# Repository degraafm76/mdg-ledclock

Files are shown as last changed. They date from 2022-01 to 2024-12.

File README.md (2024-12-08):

# MDG Ledclock model 1
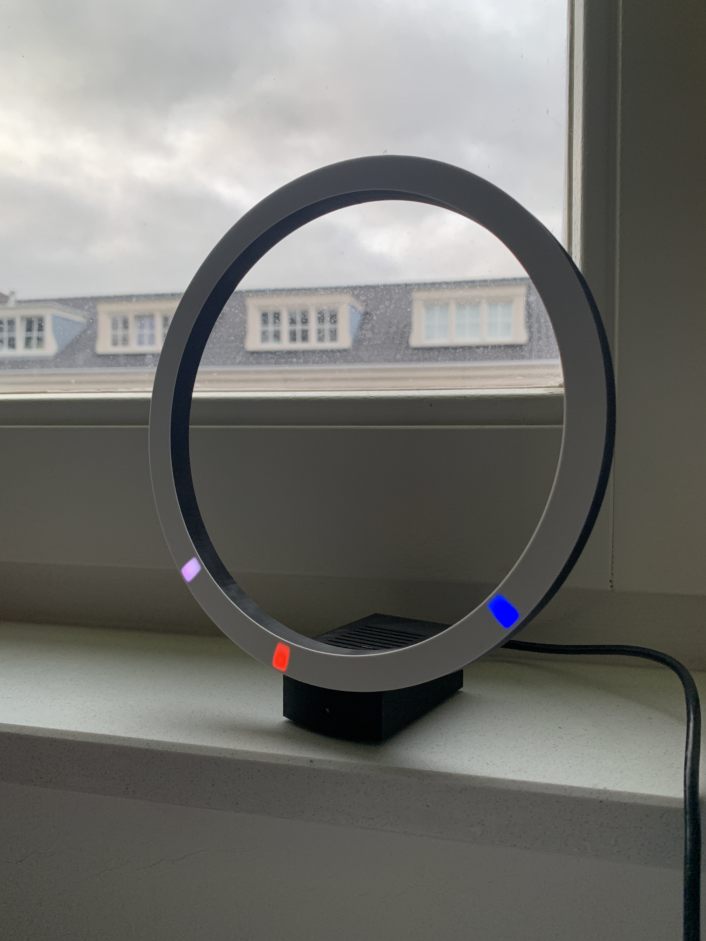
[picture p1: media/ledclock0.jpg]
MDG Ledclock

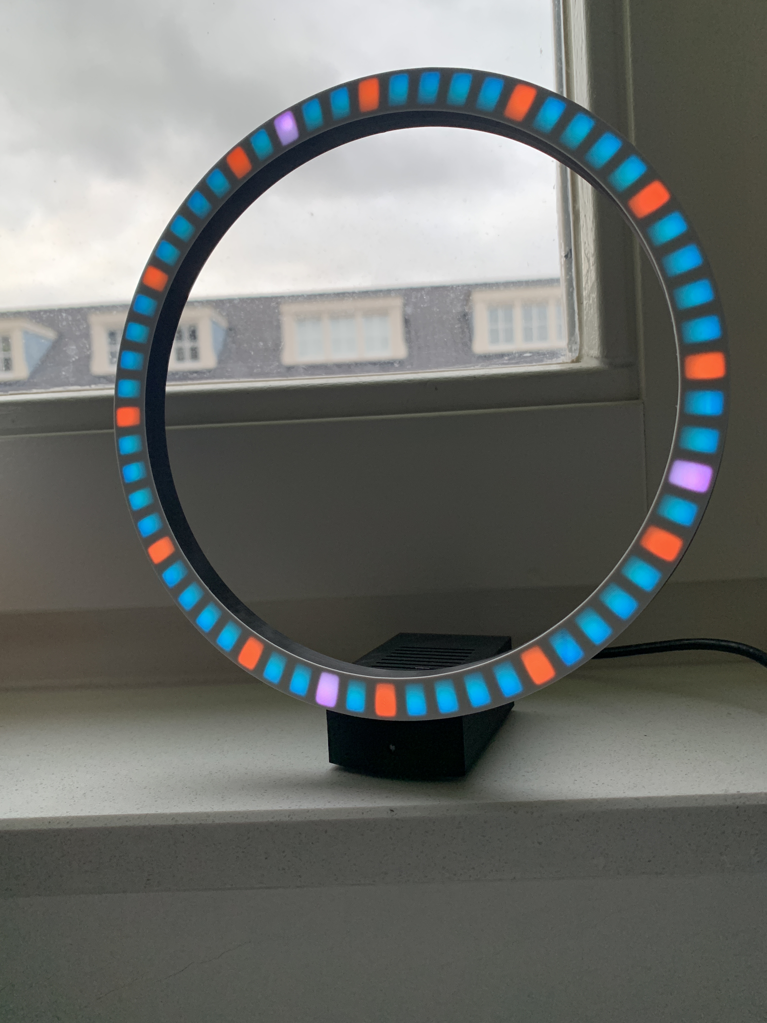
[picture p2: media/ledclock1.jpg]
MDG Ledclock

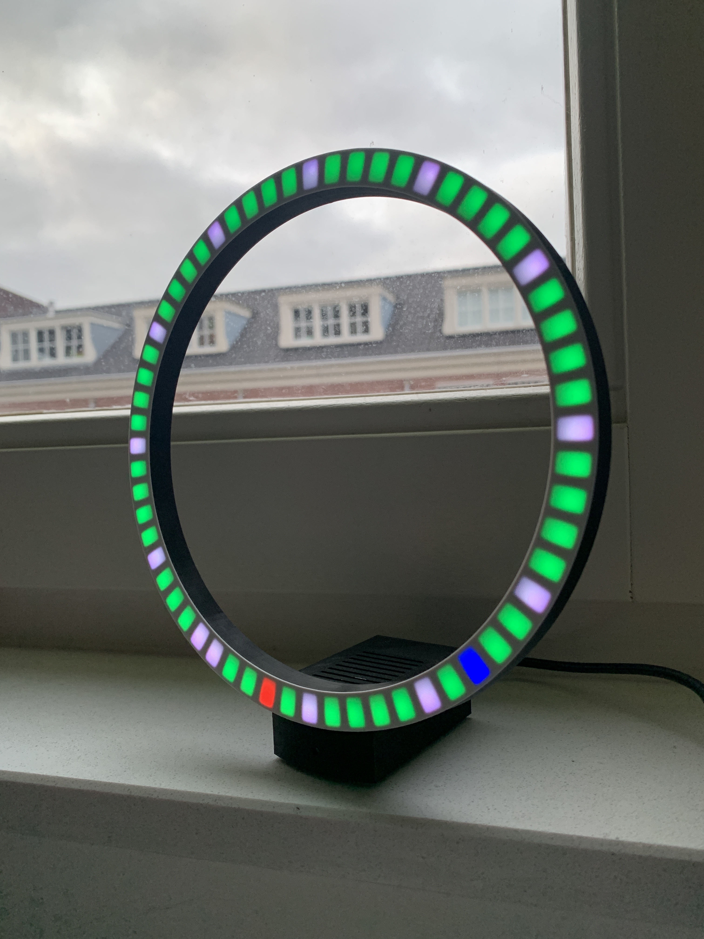
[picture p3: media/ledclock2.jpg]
MDG Ledclock

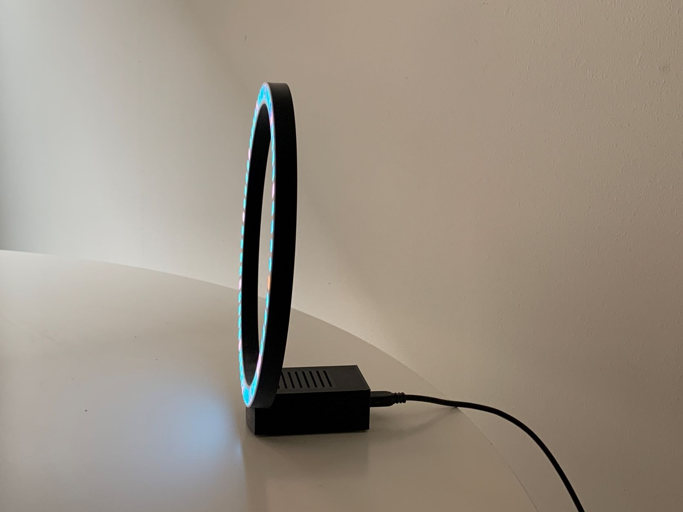
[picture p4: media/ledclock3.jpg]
MDG Ledclock


An ESP8266 based LED clock which can be controlled by HTTP and MQTT. 
Tested with Home Assistant but other domotica systems with MQTT support should work fine.

The Hardware is also compatible with the WLED project see > https://kno.wled.ge/

# Ok cool, I want one!
What are your options:

1. Buy a ready to use MDG ledclock [Etsy: MDG Led clock model 1](https://www.etsy.com/nl/listing/986543633/mdg-led-klok-model-1?ref=listings_manager_grid)
2. Source your own electronics, 3D print the parts and build it yourself.

If you like my work please consider donating to support my work.



# Electronic parts
* 1 NodeMCU ESP8266 V2
* 1 TEMT6000 Ambient light sensor
* 1 1000uF Capacitor 24V
* 1 330R 0.5W Resistor 
* 1 SK6812 LED ring 60 (https://www.tinytronics.nl/shop/nl/verlichting/ringen-en-modules/sk6812-digitale-5050-rgb-led-ring-60-leds-wit) or (https://nl.aliexpress.com/item/1005002090813354.html?gatewayAdapt=glo2nld&spm=a2g0o.9042311.0.0.27424c4dx34xlJ)
* 1 USB 5V adapter minimum 1A

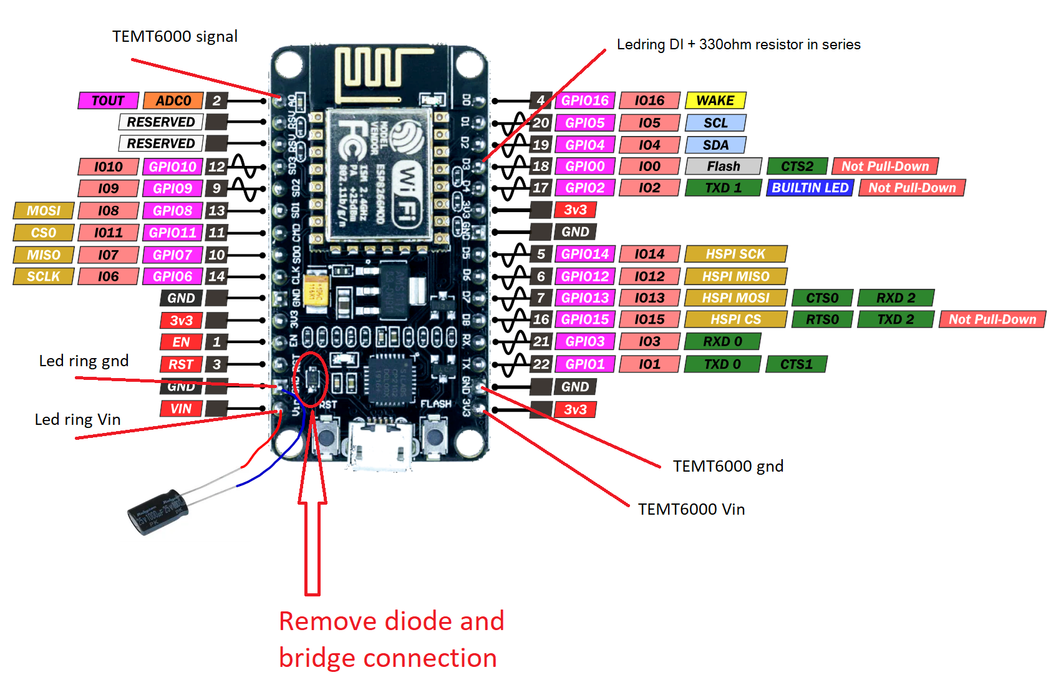
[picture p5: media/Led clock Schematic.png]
Schematic

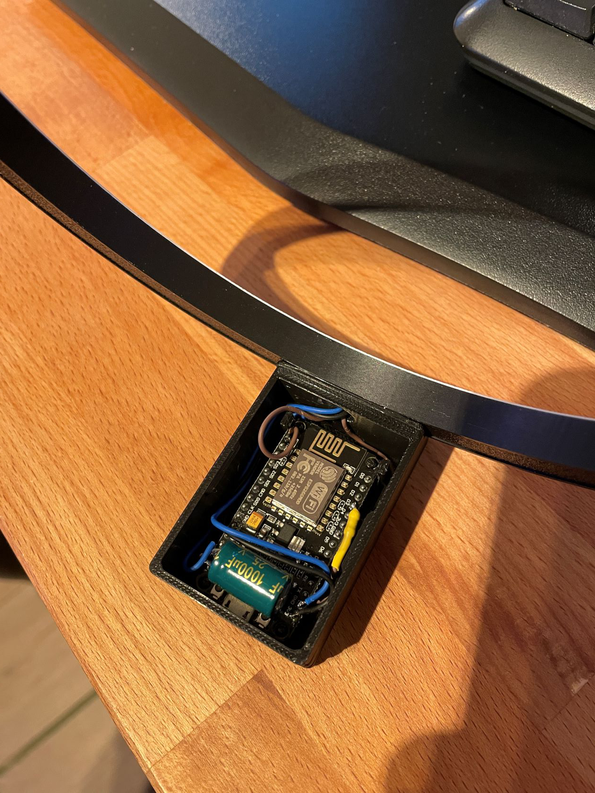
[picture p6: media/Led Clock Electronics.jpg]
Suggested wiring


# Printing parts
The parts are designed with PLA in mind. Nozzle width must be 0.4mm and layer hight 0.2mm. For the front ring and case supports on build plate are needed.

The front ring must be printed in multiple colors. The first 3 layers (0.6mm) white and the rest of the layers black. If you don't know how to print multicolor objects with your printer I suggest you take a look at: https://www.youtube.com/watch?v=1nBnVtOEAiY

The [models](https://github.com/degraafm76/mdg-ledclock/tree/main/STL) of this clock are licenced [Attribution-NonCommercial-ShareAlike 4.0 International (CC BY-NC-SA 4.0)](https://creativecommons.org/licenses/by-nc-sa/4.0/legalcode) This license lets others remix, adapt, and build upon my work non-commercially, as long as you credit me and license your new creations under the identical terms.

# Setup the clock
See https://github.com/degraafm76/mdg-ledclock/blob/main/DOC/MDG%20-%20Ledclock%20(model%201).pdf

# Serial configuration
All configuration settings (wifi/mqtt/timezone) can be set with a serial connection. Use 115200 baud

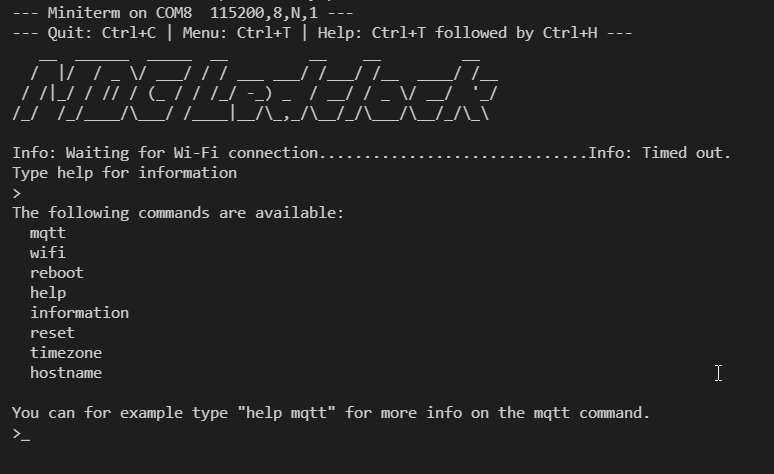
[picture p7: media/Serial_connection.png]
Serial Connection


# Update software
There are 2 options to update the clock.

1. Install Visual Studio code with platform.io and compile/upload the software to the clock. You can find the latest release here https://github.com/degraafm76/mdg-ledclock/releases
2. Download the bin file from the latest release and flash the file to the clock with ESP home flasher https://github.com/esphome/esphome-flasher/releases

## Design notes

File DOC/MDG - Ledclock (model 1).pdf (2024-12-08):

# MDG LEDCLOCK (MODEL 1)

# QUICKSTART GUIDE V1.6 12-2024

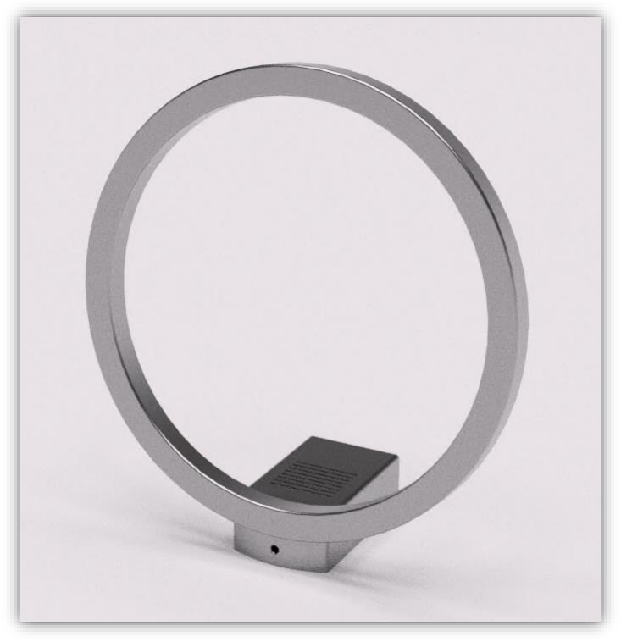
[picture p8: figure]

1 INDEX

2 INTRODUCTION

First of all thank you for buying this handmade clock which is designed and manufactured in a small workshop in the Netherlands.

I hope you have much fun using this clock!

HOW TO GET HELP

If you have any problems with this clock, please leave us a message at support@mdg-design.nl and we will try to help you out.

Latest information and software version can be found at degraafm76/mdg-ledclock (github.com) (https://github.com/degraafm76/mdg-ledclock)

A WORD OF CAUTION

The body of the clock is made on a 3D-printer with PLA plastic. PLA has a melting temperature of about 60C/140F. Please don’t leave the clock in a car on a hot summer day, or put it next to a heat source. This may deform or permanently damage your clock.

3 SETUP YOUR CLOCK

Power up your clock by connecting a micro USB cable¹ to an USB 5V power source¹ with an output of at least 1A. Most phone and tablet USB chargers should work, there is no risk in damaging the clock if an USB charger is used with an output of less than 1A but the clock won’t function correctly.

When the clock is powered on, minutes 0 to 29 will light up white and minute 30 red. This will take about 30 seconds. The red light means that there is no working Wi-Fi connection, and is expected when turning the clock on for the first time. Follow the steps in 3.1 to connect to and configure your clock.

Note: 5 seconds after the red light the clock starts running but of course not on time.

1 Not included

3.1 CONNECTING TO THE CLOCK

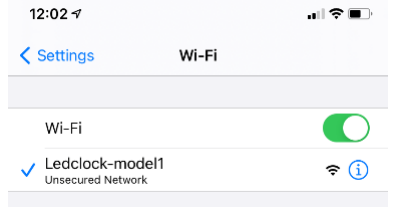
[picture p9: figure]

When the clock cannot connect to a Wi-Fi network, or the clock is not configured, the clock will start a Wi-Fi network with the
SSID ‘MDG-Ledclock1’. Connect to this Wi-Fi network from your mobile phone or pc, no Wi-Fi key is needed in the latest version of the clock (the key for older versions can be found on the bottom of the clock)
Note: do not select the option to auto connect to this network.

When you have a connection to the Wi-Fi network ‘MDG-Ledclock1’ open a browser on the device that has a connection with the Wi-Fi network ‘MDG-Ledclock1’ and go to the following URL: http://ledclock.local. When the URL http://ledclock.local doesn’t work, you can try to connect to the URL: http://192.168.4.1

*There is a know issue where the website of the clock doesn’t open in safari on the latest iPhone versions ( cannot parse error). Please use another browser such as Google Chrome until this issue is fixed.

After a couple of seconds the page as shown in below picture should appear. Open the settings page and follow the instructions in chapter 3.2 tot setup your clock.

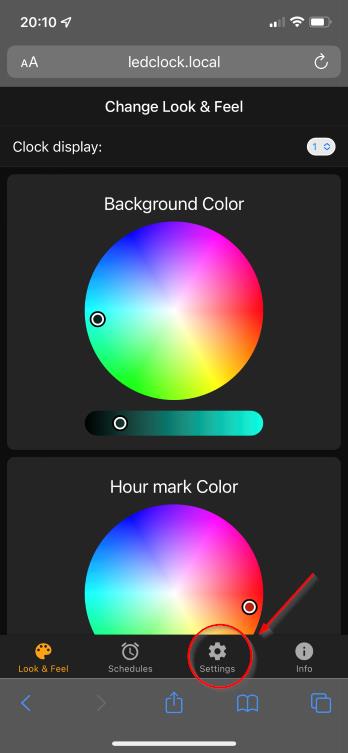
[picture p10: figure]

3.2 SETUP YOUR CLOCK

Press the Scan Networks button (1) and wait until a list of Wi-Fi networks appears. Select your Wi-Fi network and type your Wi-Fi password.

Select your time zone (2) scroll down and press the Save & Reboot button (3). You can leave the MQTT fields empty for now. Wait until you see the clock running with the correct time and continue to chapter 4

Note: It can take some time for the clock to show up after there is a Wi-Fi connection (a couple of white leds, and one green)

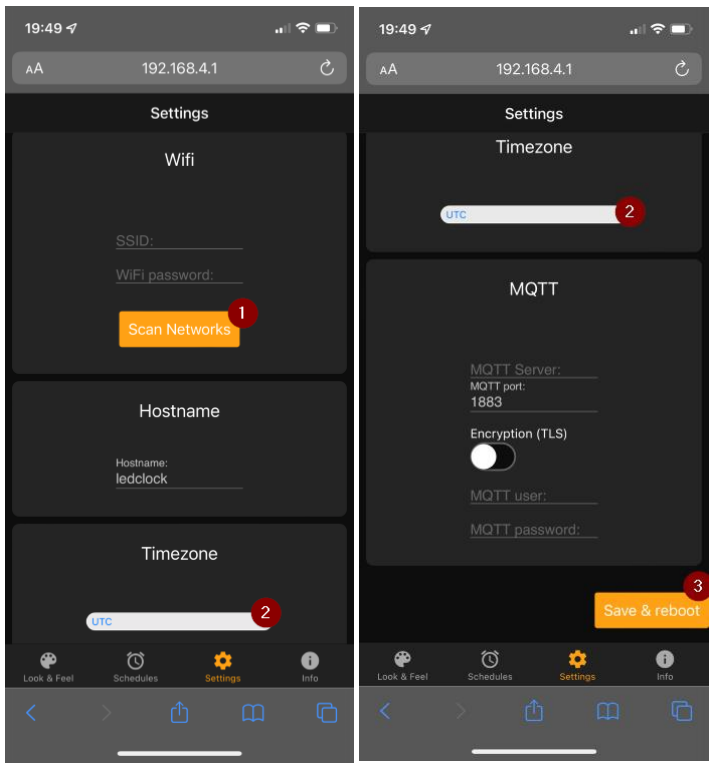
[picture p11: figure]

Optional settings*

Hostname
When needed (for example when you have multiple MDG-clocks) you can change the hostname of the clock. When changing the hostname, make sure to only use numbers and letters. Also take a note of the hostname because you need it to connect to the clock. When you change the hostname the URL becomes http://<yourhostname>.local

MQTT
MQTT configuration is optional. If you know what an MQTT client is, see chapter 5 for configuration, otherwise leave all MQTT fields default.

4 USING YOUR CLOCK

This chapter describes how you can connect to the clock, how to create different clock displays and how to create schedules to change the clock display after you have setup the clock as described in chapter 3

4.1 CONNECTING TO THE CLOCK

Open a web browser and connect to http://ledclock.local, after some time the below interface should appear¹.

1: Make sure you are disconnected from the clock’s Wi-fi network and are connected to you own Wi-Fi network. If you changed the hostname as shown in 3.2, please use this to connect to the clock for example http://yourhostname.local

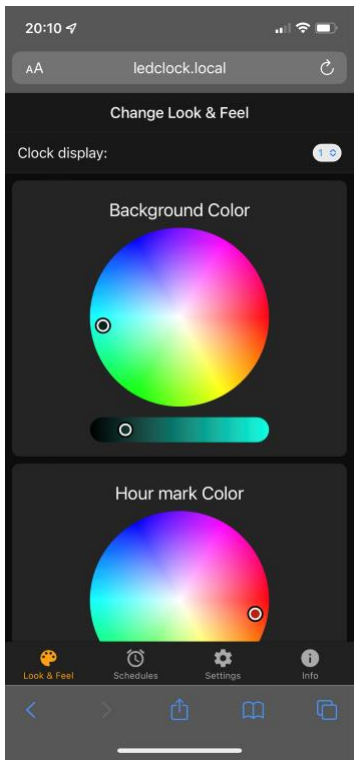
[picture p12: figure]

When the above connection method doesn’t work, lookup the clock’s IP-address in your router or DHCP server. When you have found the IP-address of the clock, connect to it with the URL http://x.x.x.x where x.x.x.x is the IP-address of your clock.

4.2 CREATE DIFFERENT CLOCK DISPLAYS

You can create 8 different clock displays and store them in the clock. First select a clock display number, change the colors and settings like auto brightness the way you want them and press the save button.

Note: Out of the box all 8 position have the same default display colors (blue background, red hours marks and white hour, minute and second hand)

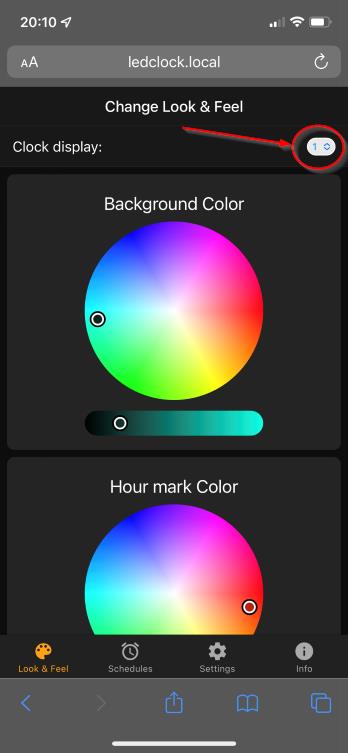
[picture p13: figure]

4.3 CHANGE DISPLAY SCHEDULES

It is possible to change the clock display at specific times. For example: you can have a bright colorful clock display during the day and a very dim display during the night.

To create a schedule open the Schedules tab and click on one of the schedules. Select the time (1) and display number (2) (one of the displays you created in 4.2) and make sure the active switch (3) is on. You can create a maximum of 12 schedules. If you like to disable a specific schedule at a later time set the active switch to off (3).

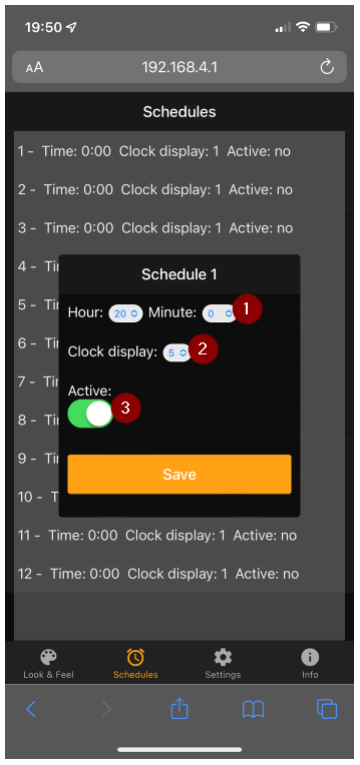
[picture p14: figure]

5 MQTT

When you have a home automation solution which can function as an MQTT broker for example Home Assistant or Homy u can optionally configure the clock as an MQTT client. This way you can control the clock with your home automation solution.

5.1 MQTT CONFIGURATION

Fill in your MQTT broker hostname or IP-address. Fill in your MQTT broker port in, default ports are 1883 (unencrypted) and 8883 (encrypted). If you have MQTT encryption configured on the broker you can enable encryption (TLS). Be aware that when TLS is enabled that the webserver will be disabled.

See chapter 5.5 for TLS notes

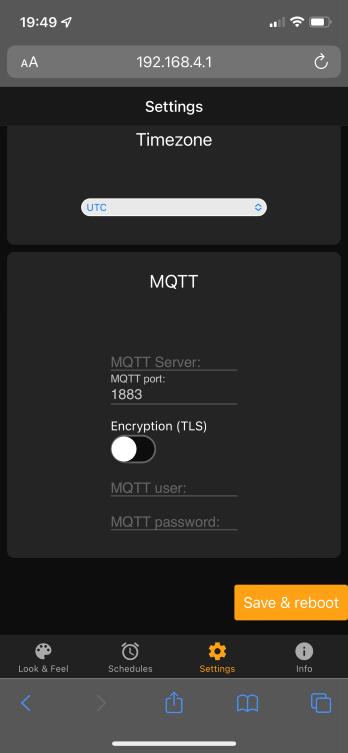
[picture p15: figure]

5.2 MQTT TOPICS

Commands over MQTT are issued to the ledclock by using the topics and JSON payloads described in this chapter. Replace [hostname] with the configured hostname this is by default: ledclock.

5.2.1 DISPLAY

Display Topics
State topic: [hostname]/display/state Command topic: [hostname]/ display /set

On/Off
JSON Payload:
{
"state": "ON|OFF"
}

5.2.2 BACKGROUND

Background Topics
State topic: [hostname]/background/state Command topic: [hostname]/background/set

On/Off
JSON Payload:
{
"state": "ON|OFF"
}

Brightness
JSON Payload:
{
"state": "ON",
"brightness": <1 to 100>
}

Color
JSON Payload:
{
"state": "ON",
"color": {
"r": 0 to 255,
"g": 0 to 255,
"b": 0 to 255
}
}

Effects
{
"state": "ON",
"effect": "<effect>"
}

Effects: <rgb, rainbow, bpm>

5.2.3 HOURMARKS

Hourmarks topics
State topic: [hostname]/hourmarks/state Command topic: [hostname]/hourmarks/set

On/Off
JSON Payload:
{
"state": "ON|OFF"
}

Brightness
JSON Payload:
{
"state": "ON",
"brightness": 1 to 100
}

Color
JSON Payload:
{
"state": "ON",
"color": {
"r": 0 to 255,
"g": 0 to 255,
"b": 0 to 255
}
}

5.2.4 HOUR

Hour topics
State topic: [hostname]/hour/state Command topic: [hostname]/hour/set

On/Off
JSON Payload:
{
"state": "ON|OFF"
}

Brightness
JSON Payload:
{
"state": "ON",
"brightness": 1 to 100
}

Color
JSON Payload:
{
"state": "ON",
"color": {
"r": 0 to 255,
"g": 0 to 255,
"b": 0 to 255
}
}

5.2.5 MINUTE

Minute topics
On/Off
JSON Payload:
{
"state": "ON|OFF"
}

Brightness
JSON Payload:
{
"state": "ON",
"brightness": 1 to 100
}

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

5.2.6 SECOND

Second topic
[hostname]/second/state
[hostname]/second/set

On/Off
JSON Payload:
{
"state": "ON|OFF"
}

Brightness
JSON Payload: {

"state": "ON",
"brightness": 1 to 100 }

Color
JSON Payload: {

"state": "ON",
"color": {
"r": 0 to 255,
"g": 0 to 255,
"b": 0 to 255
}
}

5.2.7 LIGHT SENSOR

Light sensor topic
[hostname]/ledclock/sensor

Sensor
JSON Payload: {

"lux": 1 to 1000 }

5.3 GENERIC MQTT EXAMPLES

Turn background off:

Topic: [hostname]/background/set JSON Payload:
{
"state": "OFF"
}

Set background brightness to 50%:

Topic: [hostname]/background/set JSON Payload:
{
"state": "ON",
"brightness": 50
}

Change color of hour marks to red:

Topic: [hostname]/hourmarks/set JSON Payload:
{
"state": "ON",
"color": {
"r": 255,
"g": 0,
"b": 0
}
}

5.4 HOME ASSISTANT MQTT EXAMPLE CONFIGURATION

- schema: json

command_topic: "ledclock/display/set"

state_topic: "ledclock/display/state"

name: 'Led clock'

brightness: true

brightness_scale: 100

effect: true

effect_list:

- auto_brightness
- manual_brightness
- schema: json

command_topic: "ledclock/hour/set"

state_topic: "ledclock/hour/state"

name: 'Led clock - hour hand'

brightness: true

color_mode: true

supported_color_modes: ["rgb"]

brightness_scale: 100

- schema: json

command_topic: "ledclock/minute/set"

state_topic: "ledclock/minute/state"

name: 'Led clock - minute hand'

brightness: true

color_mode: true

supported_color_modes: ["rgb"]

brightness_scale: 100

- schema: json

command_topic: "ledclock/second/set"

state_topic: "ledclock/second/state"

name: 'Led clock - second hand'

brightness: true

color_mode: true

supported_color_modes: ["rgb"]

brightness_scale: 100

- schema: json

command_topic: "ledclock/background/set"

state_topic: "ledclock/background/state"

name: 'Led clock - background'

brightness: true

color_mode: true

supported_color_modes: ["rgb"]

brightness_scale: 100

effect: true

effect_list:

- rgb
- rainbow
- bpm
- schema: json

command_topic: "ledclock/hourmarks/set"

state_topic: "ledclock/hourmarks/state"

name: 'Led clock - hourmarks'

brightness: true

color_mode: true

supported_color_modes: ["rgb"]

brightness_scale: 100

5.5 | TLS INFORMATION
| • At the moment it is not possible to upload fingerprints or certificates for server validation. • In general, TLS 1.2, TLS 1.1, and TLS 1.0 are supported with RSA and Elliptic Curve keys and a very rich set of hashing and symmetric encryption codes. • When TLS is activated the webserver is stopped however you can continue to configure the clock with a serial connection 115200 baud.

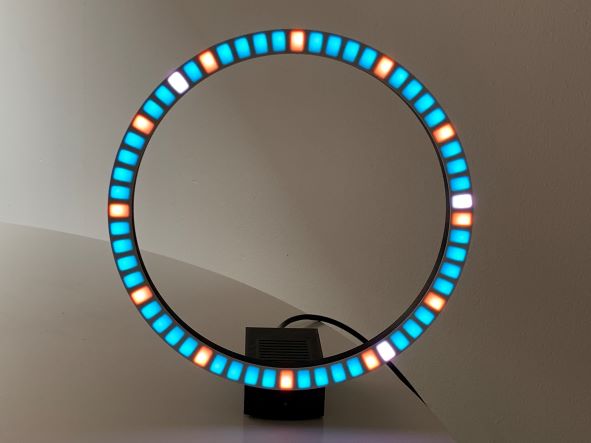
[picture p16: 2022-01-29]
media/mdg-ledclock.jpg

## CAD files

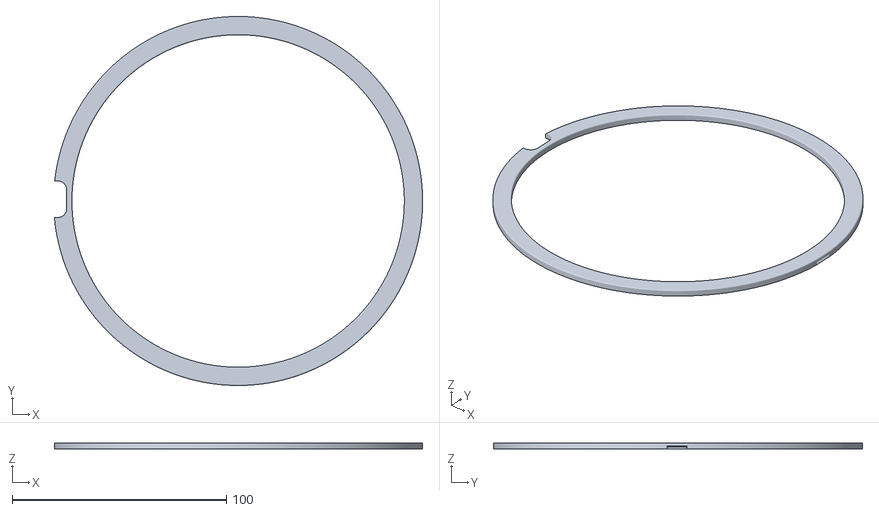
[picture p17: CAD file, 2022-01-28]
STL/Led ring back.stl
171.8 x 172.1 x 3.00

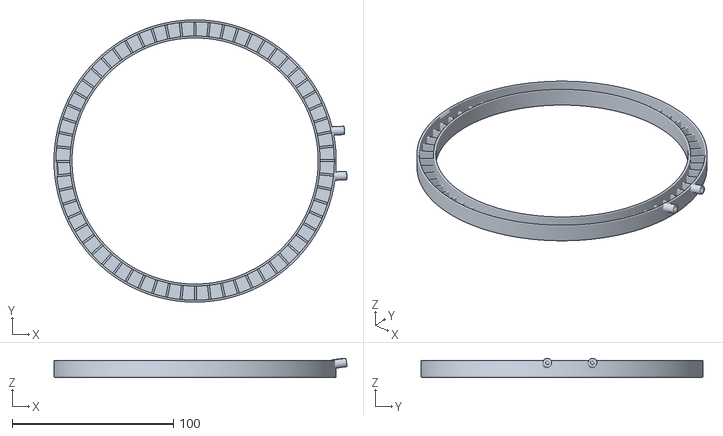
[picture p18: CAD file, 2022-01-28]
STL/Led ring front.stl
181.5 x 174.8 x 12.1

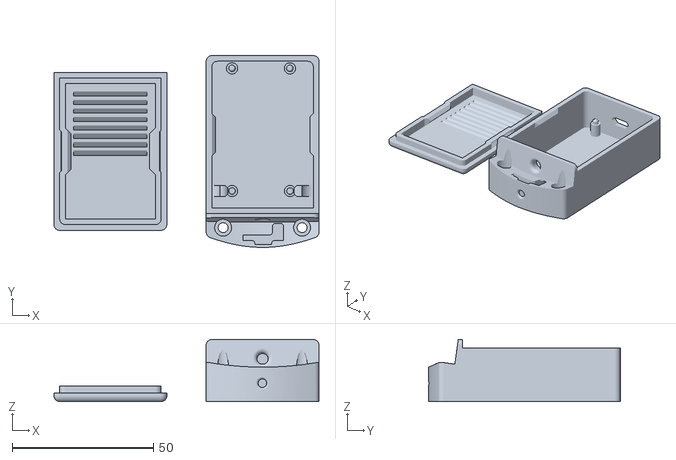
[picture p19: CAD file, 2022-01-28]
STL/Case.stl
93.9 x 68.0 x 22.0

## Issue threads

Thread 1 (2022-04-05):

Wifi password

shermanpark, 2022-04-05:
Thank you for the great project!
I printed the case, built the clock, programmed the ESP, but
I am stuck at connecting to the wifi on the clock.
I see the SSID of: MDG-Ledclock1 but I do not know the wifi key.
Please help
Never mind, I figured it out - connected via serial and typed "information"

Closed 2022-04-05.

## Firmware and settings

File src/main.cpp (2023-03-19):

/*  MDG Ledclock
	Copyright (C) 2022  M. de Graaf

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
	You should have received a copy of the GNU General Public License
	along with this program.  If not, see <http://www.gnu.org/licenses/>.
 */

#include <Arduino.h>
#include <helperfunctions.h>
#include <ezTime.h> // using modified library in /lib (changed host to timezoned.mdg-design.nl)
#include <ESP8266HTTPClient.h>
#include <ESP8266WiFi.h>
#include <ESP8266mDNS.h>
#include <FastLED.h>
#include <PubSubClient.h>
#include <ESPAsyncTCP.h>
#include <ESPAsyncWebServer.h>
#include <ArduinoJson.h>
#include <LittleFS.h>
#include <mqtt.h>
#include <http_server.h>
#include <filesystem.h>
#include <config.h>
#include <structs.h>
#include <global_vars.h>
#include <serial.h>
#include <effects.h>

void scanWifi(String ssid)
{

	byte numSsid = WiFi.scanNetworks();
	rssi = -999;
	for (int thisNet = 0; thisNet < numSsid; thisNet++)
	{
		if (WiFi.SSID(thisNet) == ssid)
		{
			if (WiFi.RSSI(thisNet) > rssi)
			{
				memcpy(bssid, WiFi.BSSID(thisNet), 6);
				channel = WiFi.channel(thisNet);
				rssi = WiFi.RSSI(thisNet);
			}
		}
	}
}

boolean checkConnection()
{
	int count = 0;
	Serial.print("Info: Waiting for Wi-Fi connection");
	while (count < 30)
	{
		leds[rotate(count)] = CRGB::White;
		FastLED.show();

		if (WiFi.status() == WL_CONNECTED)
		{
			Serial.println();
			Serial.println("Info: Connected!");
			leds[rotate(count)] = CRGB::Green;
			FastLED.show();
			return (true);
		}
		delay(500);
		Serial.print(".");
		count++;
	}
	Serial.println("Info: Timed out.");
	leds[rotate(count)] = CRGB::Red;
	FastLED.show();
	delay(5000);
	return false;
}

void setup()
{

	delay(2000); // sanity check delay - allows reprogramming if accidently blowing power w/leds

	Serial.begin(115200);

	while (!Serial)
	{
		;
	} // wait for Serial port to connect. Needed for native USB port only

	Serial.println("   __  ______  _____  __         __    __         __  ");
	Serial.println("  /  |/  / _ \\/ ___/ / / ___ ___/ /___/ /__  ____/ /__");
	Serial.println(" / /|_/ / // / (_ / / /_/ -_) _  / __/ / _ \\/ __/  '_/");
	Serial.println("/_/  /_/____/\\___/ /____|__/\\_,_/\\__/_/\\___/\\__/_/\\_\\ ");
	Serial.println();

	// Initialize LittleFS
	if (!LittleFS.begin())
	{
		// Serial.println("An Error has occurred while mounting LittleFS");
		return;
	}

	///// Config file /////
	File configfile = LittleFS.open(JSON_CONFIG_FILE, "r");
	if (!configfile)
	{
		// Serial.println("Config file open failed");
	}
	// Allocate a temporary JsonDocument
	// Don't forget to change the capacity to match your requirements.
	// Use arduinojson.org/assistant to compute the capacity.
	DynamicJsonDocument config_doc(512);

	jsonConfigfile = (configfile.readString());

	// Deserialize the JSON document
	DeserializationError error_config = deserializeJson(config_doc, jsonConfigfile);
	if (error_config)
		// Serial.println(F("Failed to read config.json file, using default configuration"));

		configfile.close(); // close file

	///// Schedule file /////
	File schedulefile = LittleFS.open(JSON_SCHEDULES_FILE, "r");
	if (!schedulefile)
	{
		// Serial.println("Schedule file open failed");
	}
	// Allocate a temporary JsonDocument
	// Don't forget to change the capacity to match your requirements.
	// Use arduinojson.org/assistant to compute the capacity.

	DynamicJsonDocument schedule_doc(128 * SCHEDULES);

	jsonSchedulefile = (schedulefile.readString());

	// Deserialize the JSON document
	DeserializationError error_schedule = deserializeJson(schedule_doc, jsonSchedulefile);
	if (error_schedule)
		// Serial.println(F("Failed to read schedule.json file, using default configuration"));

		schedulefile.close(); // close file

	for (int i = 0; i <= SCHEDULES - 1; i++)
	{
		schedules[i].active = schedule_doc[i]["a"] | 0;
		schedules[i].activeclockdisplay = schedule_doc[i]["acd"] | 0;
		schedules[i].hour = schedule_doc[i]["h"] | 0;
		schedules[i].minute = schedule_doc[i]["m"] | 0;
	}

	////// Config file //////
	File clkdisplaysfile = LittleFS.open(JSON_CLOCK_DISPLAYS_FILE, "r");

	if (!clkdisplaysfile)
	{
		// Serial.println("Clock display file open failed");
	}

	// Allocate a temporary JsonDocument
	// Don't forget to change the capacity to match your requirements.
	// Use arduinojson.org/assistant to compute the capacity.
	DynamicJsonDocument clkdisplays_doc(256 * CLOCK_DISPLAYS);

	jsonClkdisplaysfile = (clkdisplaysfile.readString());

	// Deserialize the JSON document
	DeserializationError error_clkdisplays = deserializeJson(clkdisplays_doc, jsonClkdisplaysfile);
	if (error_clkdisplays)
		// Serial.println(F("Failed to read file clkdisplays.json, using default configuration"));

		clkdisplaysfile.close(); // close file

	for (int i = 0; i <= CLOCK_DISPLAYS - 1; i++)
	{
		clockdisplays[i].backgroundColor = clkdisplays_doc[i]["bgc"] | 0x002622;
		clockdisplays[i].hourMarkColor = clkdisplays_doc[i]["hmc"] | 0xb81f00;
		clockdisplays[i].hourColor = clkdisplays_doc[i]["hc"] | 0xffe3e9;
		clockdisplays[i].minuteColor = clkdisplays_doc[i]["mc"] | 0xffe3e9;
		clockdisplays[i].secondColor = clkdisplays_doc[i]["sc"] | 0xffe3e9;
		clockdisplays[i].showseconds = clkdisplays_doc[i]["s"] | 1;
		clockdisplays[i].showminutes = clkdisplays_doc[i]["m"] | 1;
		clockdisplays[i].showhours = clkdisplays_doc[i]["h"] | 1;
		clockdisplays[i].showhourmarks = clkdisplays_doc[i]["hm"] | 1;
		clockdisplays[i].showbackground = clkdisplays_doc[i]["bg"] | 1;
		clockdisplays[i].autobrightness = clkdisplays_doc[i]["ab"] | 1;
		clockdisplays[i].brightness = clkdisplays_doc[i]["bn"] | 128;
		clockdisplays[i].backgroud_effect = clkdisplays_doc[i]["be"] | 0;
	}

	config.activeclockdisplay = config_doc["acd"] | 0;

	if (clockdisplays[config.activeclockdisplay].showhours == 0)
	{
		array_state[0] = false; // set hours off
	}
	if (clockdisplays[config.activeclockdisplay].showminutes == 0)
	{
		array_state[1] = false; // set minutes off
	}
	if (clockdisplays[config.activeclockdisplay].showseconds == 0)
	{
		array_state[2] = false; // set seconds off
	}
	if (clockdisplays[config.activeclockdisplay].showhourmarks == 0)
	{
		array_state[3] = false; // set hourmarks off
	}
	if (clockdisplays[config.activeclockdisplay].showbackground == 0)
	{
		array_state[4] = false; // set background off
	}

	strlcpy(config.tz, config_doc["tz"] | "UTC", sizeof(config.tz));
	strlcpy(config.ssid, config_doc["ssid"] | "", sizeof(config.ssid));
	strlcpy(config.wifipassword, config_doc["wp"] | "", sizeof(config.wifipassword));
	strlcpy(config.hostname, config_doc["hn"] | "ledclock", sizeof(config.hostname));
	strlcpy(config.mqttserver, config_doc["ms"] | "", sizeof(config.mqttserver));
	strlcpy(config.mqttuser, config_doc["mu"] | "", sizeof(config.mqttuser));
	strlcpy(config.mqttpassword, config_doc["mpw"] | "", sizeof(config.mqttpassword));
	config.mqttport = config_doc["mp"] | 1883;
	config.mqtttls = config_doc["mt"] | 0;

	FastLED.setBrightness(128);
	FastLED.setMaxPowerInVoltsAndMilliamps(NEOPIXEL_VOLTAGE, NEOPIXEL_MILLIAMPS); // max 1 amp power usage

	FastLED.addLeds<SK6812, DATA_PIN, GRB>(leds, NUM_LEDS) // GRB ordering is typical
														   //  .setCorrection(TypicalLEDStrip);
		.setCorrection(0xFFFFFF);						   // No correction
	FastLED.setMaxRefreshRate(0);

	// MQTT
	if (config.mqtttls == 1) // TLS enabled
	{

		TLSClient.setInsecure();
		mqttClient.setClient(TLSClient);
		mqttClient.setSocketTimeout(1);
	}
	else // TLS disabled
	{
		mqttClient.setClient(espClient);
	}

	mqttClient.setServer(config.mqttserver, config.mqttport);
	mqttClient.setCallback(callback);
	mqttClient.setSocketTimeout(1);

	// WIFI
	WiFi.mode(WIFI_STA);

	WiFi.hostname(config.hostname);

	scanWifi(config.ssid);

	if (rssi != -999) // connect to strongest ap if multiple ap's with same ssid are found
	{
		WiFi.begin(config.ssid, config.wifipassword, channel);
	}
	else
	{
		WiFi.begin(config.ssid, config.wifipassword);
	}

	if (checkConnection())
	{
		wifiConnected = true;
		waitForSync();
		MQTTconnect();
	}
	else
	{
		wifiConnected = false;
	}

	if (wifiConnected == false)
	{
		Serial.println("");
		Serial.print("Setting soft-AP ... ");
		Serial.println(WiFi.softAP(AP_NAME) ? "Ready" : "Failed!");
		Serial.println("");
		WiFi.mode(WIFI_AP); // Accespoint mode
	}

	// Provide official timezone names
	// https://en.wikipedia.org/wiki/List_of_tz_database_time_zones
	if (!tz.setCache(0))
		tz.setLocation(config.tz);

	// Route for root / web pages
	handle_webpages();

	if (config.mqtttls == 1 && MQTTConnected)
	{
		// do not start webserver when MQTT is connected with TLS because of low memory and crashes
		Serial.println("Info: Webserver is disabled because MQTT TLS is enabled");
	}
	else
	{
		// Start web server
		server.begin();
	}

	// Multicast DNS
	if (!MDNS.begin(config.hostname))
	{ // Start the mDNS responder for esp8266.local
		Serial.println("Error setting up MDNS responder!");
	}

	MDNS.addService("http", "tcp", 80);

	// printInfo();
	Serial.println("Type help for information");
	Serial.print(">");
}

void loop()
{

	if (WiFi.isConnected())
	{

		if (strlen(config.mqttserver) != 0)
		{
			if (!mqttClient.connected())
			{
				long now = millis();

				if (now - lastReconnectAttempt > 5000)
				{
#ifdef MQTT_DEBUG
					Serial.println("Try to reconnect MQTT");
#endif
					lastReconnectAttempt = now;

					// Attempt to MQTTconnect
					if (MQTTconnect())
					{
#ifdef MQTT_DEBUG
						Serial.println("Connected to MQTT");
#endif
						lastReconnectAttempt = 0;
					}
				}
			}
			else
			{
				// Client connected
				mqttClient.loop();
			}
		}
	}

	currentMillis = millis();

	events();

	MDNS.update();

	// Process Schedule every new minute
	if (currentMinute != tz.minute()) // check if a minute has passed
	{
		currentMinute = tz.minute(); // set current minute

		for (int i = 0; i <= SCHEDULES - 1; i++)
		{
			if (tz.hour() == schedules[i].hour && tz.minute() == schedules[i].minute && schedules[i].active == 1)
			{
				config.activeclockdisplay = schedules[i].activeclockdisplay;
			}
		}
	}

	if (array_state[4] && display_state) // Background on
	{
		clockdisplays[config.activeclockdisplay].showbackground = 1;
	}
	else // Background off
	{
		clockdisplays[config.activeclockdisplay].showbackground = 0;
	}

	if (clockdisplays[config.activeclockdisplay].showbackground == 1) // if background is on
	{

		if (clockdisplays[config.activeclockdisplay].backgroud_effect > 0) // show effect
		{
			EVERY_N_MILLISECONDS(20) { gHue++; }

			switch (clockdisplays[config.activeclockdisplay].backgroud_effect)
			{
			case 1:
				rainbow();
				break;
			case 2:
				bpm();
				break;
			default:
				break;
			}

			uint8_t brightness = map(array_brightness[4], 0, 100, MAX_BRIGHTNESS, MIN_BRIGHTNESS);
			for (int Led = 0; Led < NUM_LEDS; Led = Led + 1)
			{
				leds[rotate(Led)].fadeLightBy(brightness);
			}
		}
		else // Set background color
		{

			for (int Led = 0; Led < NUM_LEDS; Led = Led + 1)
			{
				leds[rotate(Led)] = clockdisplays[config.activeclockdisplay].backgroundColor;
			}
		}
	}
	else // if background is off
	{
		for (int Led = 0; Led < 60; Led = Led + 1)
		{
			leds[rotate(Led)] = 0x000000;
		}
	}

	if (array_state[3] & display_state)
	{
		clockdisplays[config.activeclockdisplay].showhourmarks = 1;
	}
	else
	{
		clockdisplays[config.activeclockdisplay].showhourmarks = 0;
	}

	if (clockdisplays[config.activeclockdisplay].showhourmarks == 1) // Hour marks
	{
		for (int Led = 0; Led <= 55; Led = Led + 5)
		{
			leds[rotate(Led)] = clockdisplays[config.activeclockdisplay].hourMarkColor;
		}
	}

	if (array_state[0] & display_state)
	{
		clockdisplays[config.activeclockdisplay].showhours = 1;
	}
	else
	{
		clockdisplays[config.activeclockdisplay].showhours = 0;
	}

	if (clockdisplays[config.activeclockdisplay].showhours == 1) // Hour hand
	{
		int houroffset = map(tz.minute(), 0, 60, 0, 5); // move the hour hand when the minutes pass

		uint8_t hrs12 = (tz.hour() % 12);
		leds[rotate((hrs12 * 5) + houroffset)] = clockdisplays[config.activeclockdisplay].hourColor;
	}

	if (array_state[1] && display_state) // Minute Hand
	{
		leds[rotate(tz.minute())] = clockdisplays[config.activeclockdisplay].minuteColor;
	}

	if (array_state[2] && display_state) // MQTT seconds on
	{
		clockdisplays[config.activeclockdisplay].showseconds = 1;
	}
	else // MQTT seconds off
	{
		clockdisplays[config.activeclockdisplay].showseconds = 0;
	}

	// Second hand
	if (clockdisplays[config.activeclockdisplay].showseconds == 1)
	{
		leds[rotate(tz.second())] = clockdisplays[config.activeclockdisplay].secondColor;
	}

	// Set Brightness
	if (clockdisplays[config.activeclockdisplay].autobrightness == 1)
	{
		// Set brightness when auto brightness is active
		if (currentMillis - lastExecutedMillis_brightness >= EXE_INTERVAL_AUTO_BRIGHTNESS)
		{
			lastExecutedMillis_brightness = currentMillis; // save the last executed time

			// subtract the last reading:
			total = total - readings[readIndex];

			// read from the sensor:
			readings[readIndex] = analogRead(LIGHTSENSORPIN);

			// add the reading to the total:
			total = total + readings[readIndex];
			// advance to the next position in the array:
			readIndex = readIndex + 1;

			// if we're at the end of the array...
			if (readIndex >= NUMREADINGS)
			{
				// ...wrap around to the beginning:
				readIndex = 0;
			}

			// calculate the average:
			average = total / NUMREADINGS;

			lux = average * 0.9765625; // 1000/1024

			int brightnessMap = map(average, 3, 40, MIN_BRIGHTNESS, MAX_BRIGHTNESS);

			brightnessMap = constrain(brightnessMap, MIN_BRIGHTNESS, MAX_BRIGHTNESS);

			sliderBrightnessValue = brightnessMap;
			FastLED.setBrightness(brightnessMap);
		}
	}
	else
	{
		sliderBrightnessValue = clockdisplays[config.activeclockdisplay].brightness;
		int brightnessMap = map(sliderBrightnessValue, 0, 255, MIN_BRIGHTNESS, MAX_BRIGHTNESS);
		brightnessMap = constrain(brightnessMap, MIN_BRIGHTNESS, MAX_BRIGHTNESS);
	}

	if (MQTTConnected)
	{
		if (currentMillis - lastExecutedMillis_lightsensorMQTT >= EXE_INTERVAL_LIGHTSENSOR_MQTT)
		{
			lastExecutedMillis_lightsensorMQTT = currentMillis; // save the last executed time
			publishSensorState();
		}
	}

	FastLED.delay(1000 / 400);

	handleSerial();
}

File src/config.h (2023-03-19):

#ifndef CONFIG_H
#define CONFIG_H

#define SOFTWARE_VERSION "1.2.1"            // Software version
#define CLOCK_MODEL "MDG Ledclock model 1"  // Clock Model
#define NUM_LEDS 60                         // How many leds are in the clock?
#define ROTATE_LEDS 30                      // Rotate leds by this number. Led ring is connected upside down
#define MAX_BRIGHTNESS 255                  // Max brightness
#define MIN_BRIGHTNESS 8                    // Min brightness (at very low brightness levels interpolating doesn't work well and the led's will flicker and not display the correct color)
#define DATA_PIN 4                          // Neopixel data pin (use pin 4 for WLED compatibility)
#define NEOPIXEL_VOLTAGE 5                  // Neopixel voltage
#define NEOPIXEL_MILLIAMPS 1000             // Neopixel maximum current usage in milliamps, if you have a powersource higher then 1A you can change this value (at your own risk!) to have brighter leds.
#define LIGHTSENSORPIN A0                   // Ambient light sensor pin
#define EXE_INTERVAL_AUTO_BRIGHTNESS 500    // Interval (ms) to check light sensor value
#define EXE_INTERVAL_LIGHTSENSOR_MQTT 60000 // Interval (ms) to send light sensor value to MQTT topic
#define CLOCK_DISPLAYS 8                    // Nr of user defined clock displays
#define SCHEDULES 12                        // Nr of user defined schedules
#define AP_NAME "MDG-Ledclock1"             // Name of the AP when WIFI is not setup or connected
//#define MQTT_DEBUG						// MQTT debug enabled
#define COMPILE_DATE __DATE__ " " __TIME__ // Compile date/time

#endif

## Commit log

2021-12-19 Fix auto brightness, stopping AP messes with ADC read. Removed AP when connected to WIFI
    [main.cpp]
2021-12-23 replaced pusub with async mqtt lib
    [main.cpp]
2022-01-09 lux sensor mqtt
2022-01-21 remove serial print bg effect
2022-01-28 Split files & clean up code
    [Case.stl, Led ring back.stl, Led ring front.stl]
2022-01-28 change led ring orientation
    [Led ring back.stl]
2022-01-29 Schematic resize
2022-01-29 add sensor mqtt topic to manual
2022-09-28 Data pin change from 3 to 4 for WLED compatibility
2023-01-16 In some case the wifi accesspoint password was less then 8 characters, this caused the accesspoint to not start

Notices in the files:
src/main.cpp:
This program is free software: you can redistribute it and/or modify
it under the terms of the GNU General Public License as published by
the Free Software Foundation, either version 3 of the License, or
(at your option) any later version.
